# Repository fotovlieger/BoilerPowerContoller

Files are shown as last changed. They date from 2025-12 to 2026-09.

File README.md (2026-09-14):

# BoilerPowerContoller (OBSOLETE, see BoilerController repo)
220V power controller that diverts excess solar power to an electric water boiler. Controller is interfaced to HomeAssistant

## Harware
- A simple electric boiler (no electronics, just a heating element and 'mechanical' thermostat)
- A cheap [thyristor voltage regulator](voltageregulator.md) with display and buttons
- Esp32 microcontroller
- temperature sensor to monitor water temperature

Note: the 'ground' ans signals to/from the power controler are connected to the 220V mains! Optocouplers an a power source for the esp32 are needed. (to be able to connect to its usp port while running or connect external (grounded) sensors)

## Software setup

- Main idea is to control the thyristor circuit by generating trigger pulses. Controlling the deleay of these pulses
  relative to the 50Hz zero crossing allows to control the output power to the boiler.
- Must be in C++: latency of micropython on esp32 is not good enough (must be better that 1ms, preferably 100us)
- interface to HASS: direct or via MQTT
- Implementation: based on EspHome, external component (replaces legacy 'custom component')

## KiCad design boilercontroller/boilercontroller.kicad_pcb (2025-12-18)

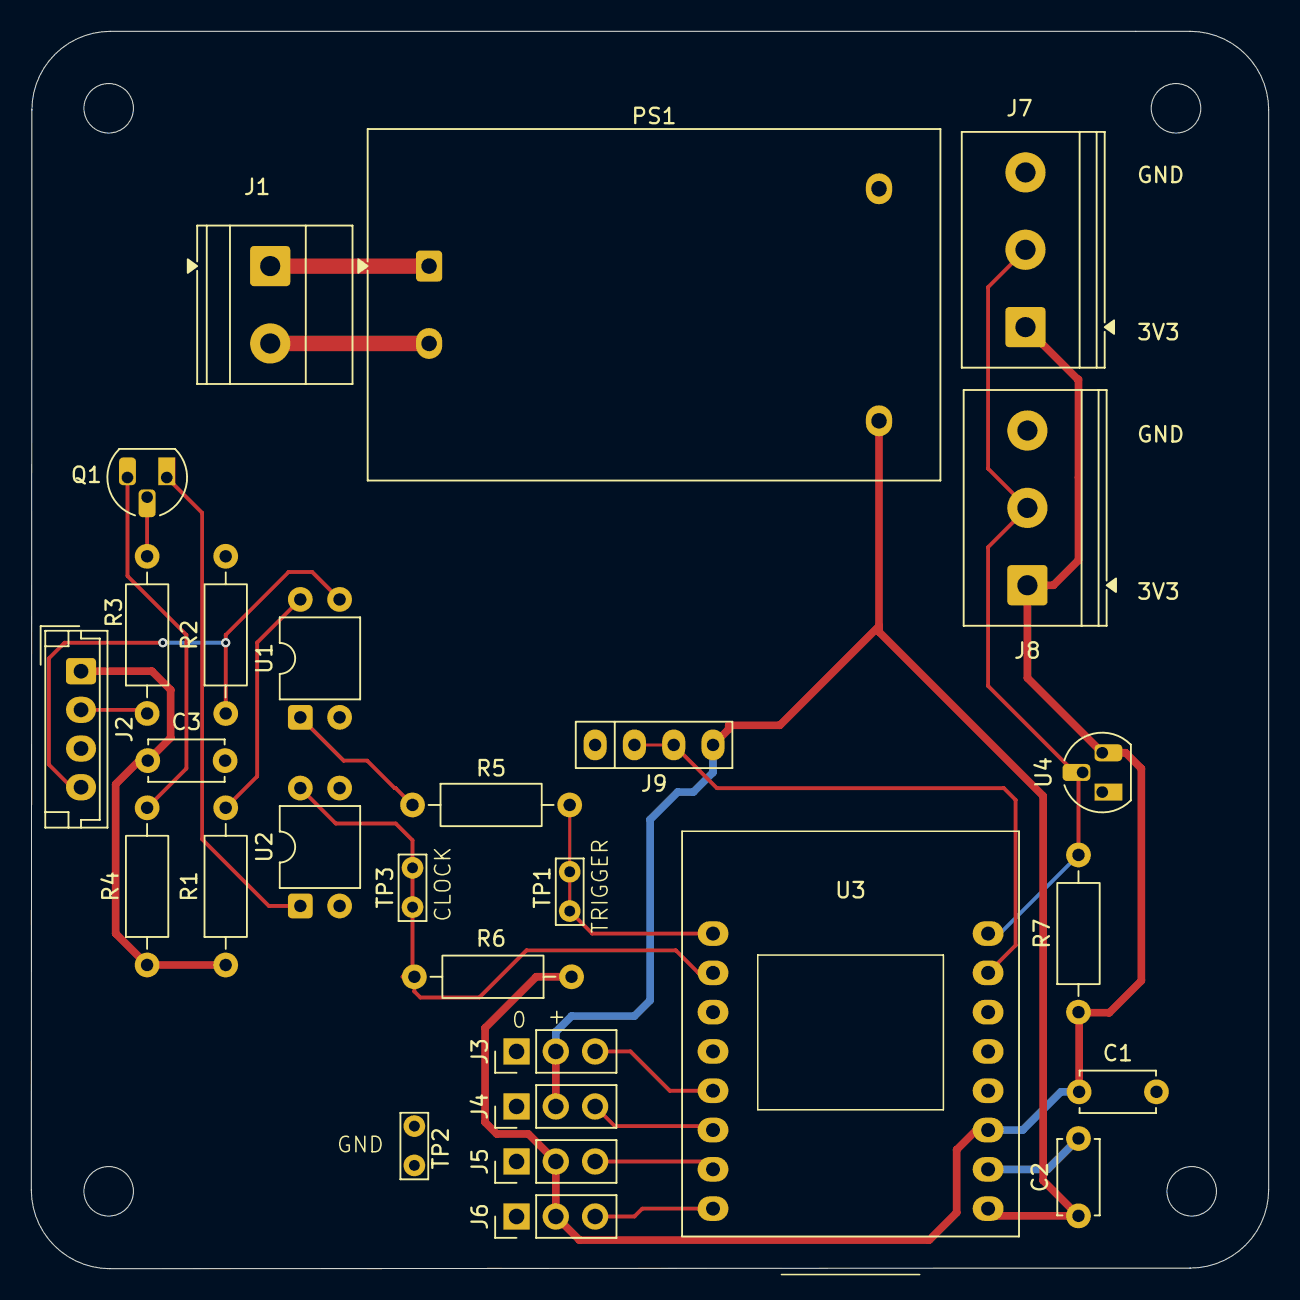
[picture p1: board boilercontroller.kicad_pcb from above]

Board: 2 copper layers, 80.0 x 80.0 mm, 32 parts (0 on the bottom side), 22 nets.

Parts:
C1, C2, C3: 100n; C_Disc_D4.7mm_W2.5mm_P5.00mm
H1, H2, H3, H4: MountingHole; MountingHole_3.2mm_M3
J1: Screw_Terminal_01x02; TerminalBlock_Phoenix_MKDS-1,5-2_1x02_P5.00mm_Horizontal
J2: Conn_01x04_Socket; JST_EH_B4B-EH-A_1x04_P2.50mm_Vertical
J3: IO7; PinHeader_1x03_P2.54mm_Vertical
J4: IO8; PinHeader_1x03_P2.54mm_Vertical
J5: IO9; PinHeader_1x03_P2.54mm_Vertical
J6: IO10; PinHeader_1x03_P2.54mm_Vertical
J7: BOILER1; TerminalBlock_Phoenix_PT-1,5-3-5.0-H_1x03_P5.00mm_Horizontal
J8: BOILER2; TerminalBlock_Phoenix_PT-1,5-3-5.0-H_1x03_P5.00mm_Horizontal
J9: Status Leds; Pad_01x04
PS1: HLK-PM01; Converter_ACDC_Hi-Link_HLK-PMxx
Q1: 2N4401; TO-92_Hans
R1: 100; R_Axial_DIN0207_L6.3mm_D2.5mm_P10.16mm_Horizontal
R2: 2k2; R_Axial_DIN0207_L6.3mm_D2.5mm_P10.16mm_Horizontal
R3: 22k; R_Axial_DIN0207_L6.3mm_D2.5mm_P10.16mm_Horizontal
R4: 1k; R_Axial_DIN0207_L6.3mm_D2.5mm_P10.16mm_Horizontal
R5: 470; R_Axial_DIN0207_L6.3mm_D2.5mm_P10.16mm_Horizontal
R6: 10k; R_Axial_DIN0207_L6.3mm_D2.5mm_P10.16mm_Horizontal
R7: 4k7; R_Axial_DIN0207_L6.3mm_D2.5mm_P10.16mm_Horizontal
TP1, TP2, TP3: TestPoint; TestPoint_Bridge_Pitch2.54mm_Drill0.7mm
U1, U2: PC817; DIP-4_W7.62mm
U3: ESP32_C3_oled
U4: DS18B20; TO-92_Hans

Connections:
+3V3: C1.1, J5.2, J6.2, J7.1, J8.1, R6.1, R7.1, U3.11 (3V3), U4.3 (V_{DD})
+5V: C2.1, J3.2, J4.2, J9.4, PS1.4 (+Vout), U3.9 (VBus)
+5V+EXT: C3.1, J2.1, R1.1, R4.1
/CLOCK: R6.2, TP3.1, U2.4, U3.2 (D4)
/D7_5V: J3.3, U3.5 (D7)
/D8_5V: J4.3, U3.6 (D8)
/D9_3V: J5.3, U3.7 (D9)
/D10_3v: J6.3, U3.8 (D10)
/SCR: J2.4, R2.1, U1.3
/STATUS_LEDS: J9.2, J9.3, U3.15 (D1)
/TRIGGER: R5.2, TP1.1, U3.1 (D3)
/ZERO: J2.2, R3.1
GND: C1.2, C2.2, J3.1, J4.1, J5.1, J6.1, J7.3, J8.3, J9.1, PS1.3 (-Vout), TP2.1, U1.2, U2.3, U3.10 (GND), U4.1 (GND)
GND_EXT: C3.2, J2.3, R2.2, U2.2
unnamed: J1.1, PS1.1 (AC/L)
unnamed: J1.2, PS1.2 (AC/N)
unnamed: J7.2, J8.2, R7.2, U3.16 (D0), U4.2 (DQ)
unnamed: Q1.2 (B), R3.2
unnamed: Q1.3 (C), R4.2
unnamed: Q1.1 (E), U2.1
unnamed: R1.2, U1.4
unnamed: R5.1, U1.1

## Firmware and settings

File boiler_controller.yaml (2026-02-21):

# 0 avoid (boot mode)
# 1: led strip
# 2: avoid: boot???
# 3,4: power dimmer
# 5,6: I2c (internal, display)
# 7: temperatures
# 8,9: never (flash)
# 10: led

esphome:
  name: boiler-controller-v4
  on_boot:
    - priority: -100
      then:
        - light.turn_on:
            id: boiler_status_leds
            brightness: 50%
            effect: "Boiler Status"

wifi:
  id: wifi_component
  ssid: !secret wifi_ssid
  password: !secret wifi_password
  power_save_mode: none

logger:

api:
  id: api_server

ota:
  - platform: esphome
    password: !secret ota_password

web_server:
  port: 80

esp32:
  variant: ESP32C3
  board: esp32-c3-devkitm-1
  framework:
    type: esp-idf

one_wire:
  - platform: gpio
    pin: GPIO0         # one wire pin
    id: one_wire_bus

sensor:
  - platform: dallas_temp
    one_wire_id: one_wire_bus
    name: "Boiler Box Temperature"
    id: boiler_box_temp
    address:  0x9e3cffb556a05328
    update_interval: 9s
  - platform: dallas_temp
    one_wire_id: one_wire_bus
    name: "boiler top temperature"
    id: boiler_temp_top
    address:  0x9050d7d4458bc828
    update_interval: 9s
  - platform: dallas_temp
    one_wire_id: one_wire_bus
    name: "boiler bottom temperature"
    id: boiler_temp_bottom
    address:  0xa700000015074f28
    update_interval: 9s

external_components:
  - source: ./external

number:
  - platform: template
    name: "Power percent"
    id: power_percent
    min_value: 0
    max_value: 100
    step: .1
    optimistic: true

select:
  - platform: template
    name: "Power mode"
    id: power_mode
    optimistic: true
    options:
      - "Off"
      - "On"
      - "Auto"
      - "Manual"

my_component:
  id: boiler_controller
  power: power_percent
  mode: power_mode
  clock: GPIO4
  trigger: GPIO3

light: 
  # todo Addressable Lambda Effect
  - platform: esp32_rmt_led_strip
    pin: GPIO1
    num_leds: 2
    name: "Boiler staus Leds"
    id: boiler_status_leds
    chipset: WS2812
    rgb_order: GRB
    effects:
    # Example 1: Show WiFi and API connection status
    - addressable_lambda:
        name: "Boiler Status"
        update_interval: 500ms
        lambda: |-
          // LED 0: WiFi status
          if (id(wifi_component).is_connected()) {
            it[0] = Color(0, 255, 0);  // Green = connected
          } else {
            it[0] = Color(255, 0, 0);  // Red = disconnected
          }
          
          // LED 1: boiler mode
          std::string m = id(power_mode).current_option();
          if (m=="Off") {
            it[1] = Color(255, 0, 0);
          } 
          else if (m=="On") {
            it[1] = Color(0, 255, 0);
          } 
          else if (m=="Manual") {
            it[1] = Color(255, 255, 0);
          }           
          else if (m=="Auto") {
            it[1] = Color(0, 0, 255);
          } 


# LCD bus I2C
i2c:
  sda: GPIO5
  scl: GPIO6
  scan: true
  id: bus_a
  frequency: 800kHz

# Font
font:
  - file: "gfonts://Roboto"
    id: my_font
    size: 12
  - file: fonts/JetBrainsMono-Light.ttf
    id: nerd
    size: 16

# Display settings
display:
  - platform: ssd1306_i2c
    model: "sh1106 128x64"
    address: 0x3C
    id: my_display
    update_interval: 2s
    rotation: 0
    offset_y: 0
    offset_x: 0
    lambda: |-
      it.fill(Color::BLACK);
      it.print(27, 20, id(my_font), "ABCDEFG");
      it.printf(27, 40, id(nerd), "B:%.1f C", id(boiler_box_temp).state);
      //it.line(27, 20, 127+27, 63+20, Color::WHITE);
      //it.line(127, 0, 0, 63, Color::WHITE);

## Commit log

2025-10-29 Update hardware section in README.md
    Clarified hardware description for the power controller.
2025-10-29 Create documentation for voltage regulator
    Added initial documentation for the voltage regulator.
2025-10-29 Fix link to thyristor voltage regulator documentation
2025-12-18 kicad files. todo: add libraries
    [boilercontroller.kicad_pcb, boilercontroller.kicad_sch]
2026-02-21 Revise boiler-controller configuration and sensors
    Updated boiler controller configuration with new parameters and additional temperature sensor.
    [boiler_controller.yaml]
2026-02-21 Refactor MyComponent to use current_option for mode
